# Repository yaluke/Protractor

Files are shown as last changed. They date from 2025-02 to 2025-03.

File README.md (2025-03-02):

The Protractor is a specialized device designed to measure rotation angles with high precision and transmit these measurements via USB to a host computer. It incorporates a precise encoder capable of measuring angles with a 1-degree precision. The Raspberry Pi Pico is used to read the encoder signal at high speed through Programmable I/O (PIO), while the TinyUSB library facilitates data sharing with the host. The Protractor was developed primarily to address the need for precise measurement of the rotation angle of a physical steering wheel in car driving simulations.

https://www.hackster.io/luke35/protractor-e2c351

https://hackaday.io/project/202539-protractor

## Hardware components

* Raspberry Pi Pico H (https://www.raspberrypi.com/products/raspberry-pi-pico/)
* Incremental Photoelectric Rotary Encoder - 400P/R (https://www.dfrobot.com/product-1601.html)
* Pico Proto board (https://shop.pimoroni.com/products/pico-proto?variant=32369530110035)
* 4-digit 7-segment display based on TM1637 (https://www.instructables.com/How-to-Use-the-TM1637-Digit-Display-With-Arduino/) (optional)
* Tact switch for reseting angle value (optional)
* Plug/socket, 10 kOhm resistors, cables, etc.

## Software Stack

To provide the required functionality, the platform needed to support fast I/O and easy USB handling. Initial experiments with direct GPIO usage for reading encoder signals showed that signals could be partially lost during rapid rotation, as direct GPIO can only handle changes up to ~10kHz. A much better and faster option was to use the Programmable Input/Output (PIO) functionality available on the Raspberry Pi Pico.

Initially, I planned to use the simplest software option - MicroPython, but it lacked direct support for USB functionality. CircuitPython was the second candidate, but it didn't have full PIO support. Finally, I chose C++ as it offers good USB support for the Raspberry Pi Pico (TinyUSB library) as well as PIO capabilities.

I based the implementation on the hid_composite example from the TinyUSB library and removed all sub-devices from the implementation except for the generic input/output device. I completed the code with a simple class handling the TM1637-based display and an Encoder C++ class with custom PIO code for handling encoder signals.

For development, I used Microsoft Visual Studio Code with the official Raspberry Pi Pico extension (on both macOS and Windows).

List of components:
* Visual Studio Code (https://code.visualstudio.com/)
* Raspberry Pi Pico extension (https://github.com/raspberrypi/pico-vscode) (installed from extensions list in VS Code)
* Raspberry Pi Pico PIO (https://hackspace.raspberrypi.com/articles/what-is-programmable-i-o-on-raspberry-pi-pico)
* TinyUSB library (https://github.com/raspberrypi/tinyusb/blob/pico/docs/getting_started.md) (installed by RPi Pico extension as a part of Pico SDK)

## Encoder Signal Processing

The encoder generates a two-phase orthogonal pulse signal, with 400 pulses per rotation for each phase. Decoding of this signal is performed by a PIO program (in the file encoder.pio) that waits for a rising edge on channel A, and then checks the value on channel B: for 0, IRQ 0 is generated; for 1, IRQ 1 is generated. These interrupts are handled by the Encoder C++ class: IRQ 0 decreases the rotation counter, while IRQ 1 increases it. This configuration generates 400 impulses per rotation, and the counter value needs to be multiplied by 360/400 = 0.9 to represent the value in degrees.

The precision of the measurement can be increased to 1600 pulses per rotation by adding three more PIO programs: one waiting for the falling edge on channel A, another waiting for the rising edge on channel B, and a third waiting for the falling edge on channel B.

## USB Communication

The USB handling implementation is based on the hid_composite example from the TinyUSB library. All device types except generic input/output devices were removed from the original code. The implementation can be tested on a host device using two examples from the tests directory:
* test_hid.py, which uses the hid library (https://pypi.org/project/hid/)
* test_pyusb.py, which uses the pyusb library (https://pypi.org/project/pyusb/)

## Build Instructions

### Connections

Encoder <-> RPi Pico
* VCC (red) <-> VBus [pin 40] (5V)
* GND (black) <-> GND [e.g. pin 38]
* channel A (white) <-> GP2 [pin 4] + 10 kOhm pull-up resistor to 3V3 [pin 36]
* channel B (green) <-> GP3 [pin 5] + 10 kOhm pull-up resistor to 3V3 [pin 36]

TM1637 display <-> RPi Pico
* CLK <-> 5 [pin 7]
* DIO <-> 4 [pin 6]
* VCC <-> 3V3 [pin 36]
* GND <-> GND [e.g. pin 38]

Reset switch <-> RPi Pico
* 3V3 [pin 36]
* GP14 [pin 19]

### Case

Simple device case and plug-in case, designed in OpenSCAD, are available in case directory on GitHub.

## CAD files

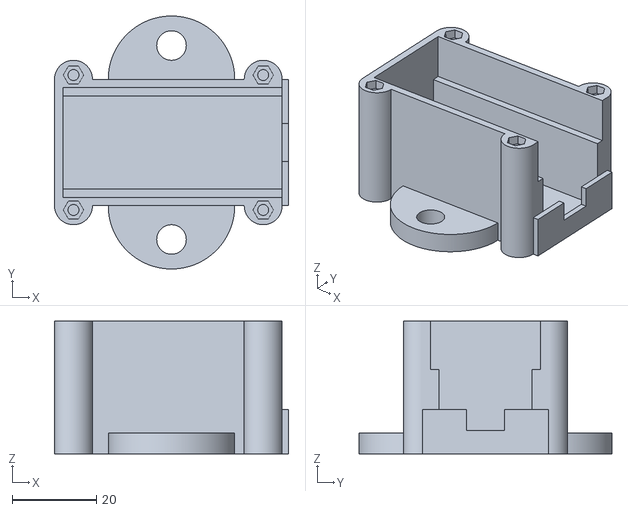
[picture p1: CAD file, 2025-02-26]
case/case_bottom.stl
55.5 x 60.0 x 31.5

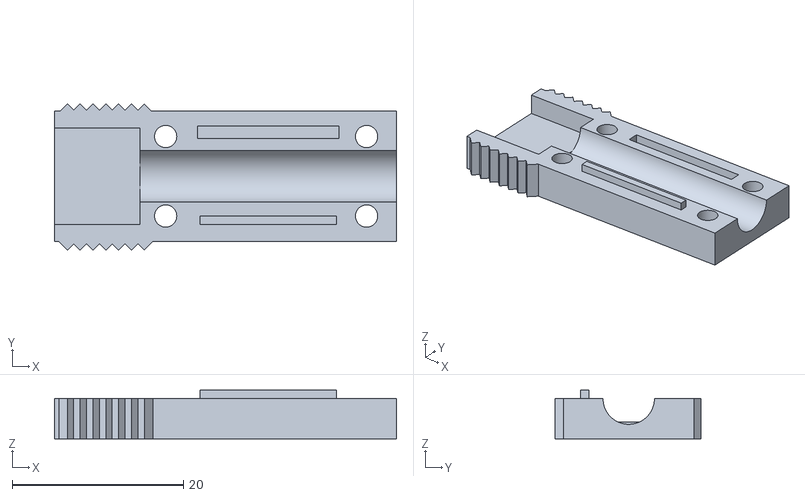
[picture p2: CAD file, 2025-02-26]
case/plug.stl
40.0 x 17.1 x 5.70

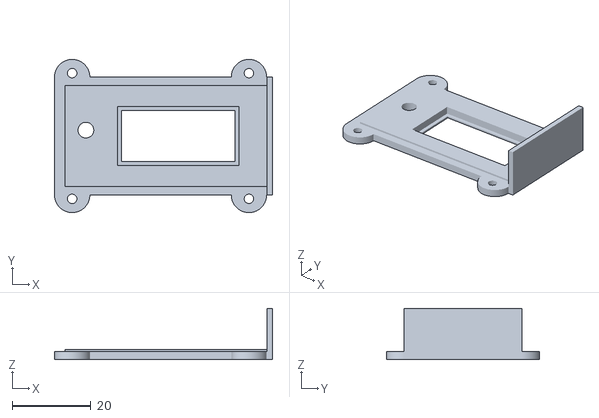
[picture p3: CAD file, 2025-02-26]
case/case_top.stl
55.5 x 39.0 x 13.0

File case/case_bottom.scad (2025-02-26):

//
// The MIT License (MIT)
//
// Copyright (c) 2025 Lukasz Ronka
//
// Permission is hereby granted, free of charge, to any person obtaining a copy
// of this software and associated documentation files (the "Software"), to deal
// in the Software without restriction, including without limitation the rights
// to use, copy, modify, merge, publish, distribute, sublicense, and/or sell
// copies of the Software, and to permit persons to whom the Software is
// furnished to do so, subject to the following conditions:
//
// The above copyright notice and this permission notice shall be included in
// all copies or substantial portions of the Software.
//
// THE SOFTWARE IS PROVIDED "AS IS", WITHOUT WARRANTY OF ANY KIND, EXPRESS OR
// IMPLIED, INCLUDING BUT NOT LIMITED TO THE WARRANTIES OF MERCHANTABILITY,
// FITNESS FOR A PARTICULAR PURPOSE AND NONINFRINGEMENT. IN NO EVENT SHALL THE
// AUTHORS OR COPYRIGHT HOLDERS BE LIABLE FOR ANY CLAIM, DAMAGES OR OTHER
// LIABILITY, WHETHER IN AN ACTION OF CONTRACT, TORT OR OTHERWISE, ARISING FROM,
// OUT OF OR IN CONNECTION WITH THE SOFTWARE OR THE USE OR OTHER DEALINGS IN
// THE SOFTWARE.
//
 
$fa=1;
$fs=0.1;
difference(){
    union() {
        //base
        cube([55.5, 30, 31.5]);
        //2 handlers
        translate([55.5/2, 0, 0]) cylinder(5, 15, 15);
        translate([55.5/2, 30, 0]) cylinder(5, 15, 15);
        //4 top screws
        translate([4.5, 0, 0]) cylinder(31.5, 4.5, 4.5);
        translate([49.5, 0, 0]) cylinder(31.5, 4.5, 4.5);
        translate([4.5, 30, 0]) cylinder(31.5, 4.5, 4.5);
        translate([49.5, 30, 0]) cylinder(31.5, 4.5, 4.5);
    }
    //bottom of the box
    translate([2, 4, 2]) cube([52, 22, 30]);
    //top part of the box
    translate([2, 2, 20]) cube([52, 26, 25]);
    //2 holes in handlers 
    translate([55.5/2, 38, -1]) cylinder(7, 3.5, 3.5);
    translate([55.5/2, -8, -1]) cylinder(7, 3.5, 3.5);
    //4 holes for top screws
    translate([4.5,-1,7]) cylinder(25, 1.3, 1.3);
    translate([49.5,-1,7]) cylinder(25, 1.3, 1.3);
    translate([4.5,31,7]) cylinder(25, 1.3, 1.3);
    translate([49.5,31,7]) cylinder(25, 1.3, 1.3);
    //4 holes for nuts
    translate([4.5,-1,29.3]) cylinder(3, 2.4, 2.5, $fa=60);
    translate([49.5,-1,29.3]) cylinder(3, 2.4, 2.5, $fa=60);
    translate([4.5,31,29.3]) cylinder(3, 2.4, 2.5, $fa=60);
    translate([49.5,31,29.3]) cylinder(3, 2.4, 2.5, $fa=60);
    //hole for usb plug
    translate([53.5,10.5,5.5]) cube([2.5, 9, 27]);
    //hole for encoder plug
    translate([53.99,-1,10.5]) cube([2.5, 32, 22]);

}

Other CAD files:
case/case_top.scad
case/plug.scad

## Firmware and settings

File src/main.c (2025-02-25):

/*
 * The MIT License (MIT)
 *
 * Copyright (c) 2019 Ha Thach (tinyusb.org)
 * Copyright (c) 2025 Lukasz Ronka (for modifications)
 *
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
 */

#include <stdlib.h>
#include <stdio.h>
#include <string.h>

#include "bsp/board_api.h"
#include "tusb.h"

#include "usb_descriptors.h"

#include "TM1637.h"
#include "encoder.h"

const uint RESET_BTN_PIN = 14;
//--------------------------------------------------------------------+
// MACRO CONSTANT TYPEDEF PROTYPES
//--------------------------------------------------------------------+

/* Blink pattern
 * - 250 ms  : device not mounted
 * - 1000 ms : device mounted
 * - 2500 ms : device is suspended
 */
enum  {
  BLINK_NOT_MOUNTED = 250,
  BLINK_MOUNTED = 1000,
  BLINK_SUSPENDED = 2500,
};

static uint32_t blink_interval_ms = BLINK_NOT_MOUNTED;

void led_blinking_task(void);
void hid_task(int16_t);

void reset_btn_cb(uint gpio, uint32_t events)
{
    if(gpio == RESET_BTN_PIN)
    {
        Encoder_reset_angle();
    }
}

/*------------- MAIN -------------*/
int main(void)
{
  board_init();

  // init device stack on configured roothub port
  tud_init(BOARD_TUD_RHPORT);

  //display
  TM1637_init(5, 4, 2);

  //encoder
  Encoder_init(2, 3, 1000000);

  //reset button
  gpio_init(RESET_BTN_PIN);
  gpio_set_dir(RESET_BTN_PIN, GPIO_IN);
  gpio_pull_down(RESET_BTN_PIN);
  gpio_set_irq_enabled_with_callback(RESET_BTN_PIN, GPIO_IRQ_EDGE_FALL, true, &reset_btn_cb);


  if (board_init_after_tusb) {
    board_init_after_tusb();
  }

  int16_t value;

  while (true)
  {
    tud_task(); // tinyusb device task
    led_blinking_task();

    value = Encoder_get_angle();

    hid_task(value);
    TM1637_showNumber(value);
  }
}

//--------------------------------------------------------------------+
// Device callbacks
//--------------------------------------------------------------------+

// Invoked when device is mounted
void tud_mount_cb(void)
{
  blink_interval_ms = BLINK_MOUNTED;
}

// Invoked when device is unmounted
void tud_umount_cb(void)
{
  blink_interval_ms = BLINK_NOT_MOUNTED;
}

// Invoked when usb bus is suspended
// remote_wakeup_en : if host allow us  to perform remote wakeup
// Within 7ms, device must draw an average of current less than 2.5 mA from bus
void tud_suspend_cb(bool remote_wakeup_en)
{
  (void) remote_wakeup_en;
  blink_interval_ms = BLINK_SUSPENDED;
}

// Invoked when usb bus is resumed
void tud_resume_cb(void)
{
  blink_interval_ms = tud_mounted() ? BLINK_MOUNTED : BLINK_NOT_MOUNTED;
}

//--------------------------------------------------------------------+
// USB HID
//--------------------------------------------------------------------+

static void send_hid_report(uint8_t report_id, int16_t value)
{
  // skip if hid is not ready yet
  if ( !tud_hid_ready() ) return;

  switch(report_id)
  {
    case REPORT_ID_GENERIC_INOUT:
    {
      // uint8_t report_id, void const* report, uint16_t len
      tud_hid_report(REPORT_ID_GENERIC_INOUT, &value, 2);
    }
    break;
  }
}

// Every 10ms, we will sent 1 report for each HID profile (keyboard, mouse etc ..)
// tud_hid_report_complete_cb() is used to send the next report after previous one is complete
void hid_task(int16_t value)
{
  // Poll every 10ms
  const uint32_t interval_ms = 10;
  static uint32_t start_ms = 0;

  if ( board_millis() - start_ms < interval_ms) return; // not enough time
  start_ms += interval_ms;

  uint32_t const btn = board_button_read();

  // Remote wakeup
  if ( tud_suspended() && btn )
  {
    // Wake up host if we are in suspend mode
    // and REMOTE_WAKEUP feature is enabled by host
    tud_remote_wakeup();
  }else
  {
    // Send the 1st of report chain, the rest will be sent by tud_hid_report_complete_cb()
    send_hid_report(REPORT_ID_GENERIC_INOUT, value);
  }
}

// Invoked when sent REPORT successfully to host
// Application can use this to send the next report
// Note: For composite reports, report[0] is report ID
void tud_hid_report_complete_cb(uint8_t instance, uint8_t const* report, uint16_t len)
{
  (void) instance;
  (void) len;

  uint8_t next_report_id = report[0] + 1u;

  if (next_report_id < REPORT_ID_COUNT)
  {
    send_hid_report(next_report_id, board_button_read());
  }
}

// Invoked when received GET_REPORT control request
// Application must fill buffer report's content and return its length.
// Return zero will cause the stack to STALL request
uint16_t tud_hid_get_report_cb(uint8_t instance, uint8_t report_id, hid_report_type_t report_type, uint8_t* buffer, uint16_t reqlen)
{
  // TODO not Implemented
  (void) instance;
  (void) report_id;
  (void) report_type;
  (void) buffer;
  (void) reqlen;

  return 0;
}

// Invoked when received SET_REPORT control request or
// received data on OUT endpoint ( Report ID = 0, Type = 0 )
void tud_hid_set_report_cb(uint8_t instance, uint8_t report_id, hid_report_type_t report_type, uint8_t const* buffer, uint16_t bufsize)
{
  (void) instance;
}

//--------------------------------------------------------------------+
// BLINKING TASK
//--------------------------------------------------------------------+
void led_blinking_task(void)
{
  static uint32_t start_ms = 0;
  static bool led_state = false;

  // blink is disabled
  if (!blink_interval_ms) return;

  // Blink every interval ms
  if ( board_millis() - start_ms < blink_interval_ms) return; // not enough time
  start_ms += blink_interval_ms;

  board_led_write(led_state);
  led_state = 1 - led_state; // toggle
}
